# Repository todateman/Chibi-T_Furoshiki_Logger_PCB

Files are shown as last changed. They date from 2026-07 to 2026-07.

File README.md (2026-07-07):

# Chibi-T Furoshiki Logger

M5Stack Basic / Core2 用の車両データロガー拡張基板（モジュール基板）です。

## 概要

本基板は M5Stack の M-BUS コネクタに接続するボトムモジュールとして動作し、以下のデータを収集・記録するためのロガー回路です。

- GNSS（GPS）モジュールからの位置情報（UART）
- 車両 ECU との UART 通信によるデータ
- BME280 センサーによる温湿度・気圧などの環境データ

## 特徴

- M5Stack M-BUS（2×15ピン）接続、Basic / Core2 の両方に対応した Module 基板
  - テンプレートは <https://github.com/botanicfields/KiCad6-Environment> の `M5Stack_module_fdm` を使用
- GNSS（GPS）モジュール接続用の UART 入力
- 車両 ECU との通信用 UART 入力
- Bosch BME280 搭載（I2C接続、アドレス `0x76`）による温湿度・気圧センシング
- MP1584EN-LF-Z による +12V → 5V / 3.3V 降圧レギュレータを内蔵
- ポリヒューズおよびショットキーダイオードによる電源保護

<!-- TODO: 基板写真・回路図スクリーンショットを追加 -->

## 主要部品

| Ref | 部品 | 役割 |
| --- | --- | --- |
| U1 | MP1584EN-LF-Z | 降圧DC-DCコンバータ（+12V → 5V/3.3V） |
| U2 | BME280 | 温湿度・気圧センサー（I2C） |
| J1 | M5Stack M-BUS | M5Stack Basic/Core2 との接続コネクタ |
| D1 | ショットキーダイオード | 電源保護 |
| F1 | ポリヒューズ | 電源保護 |

より詳細な部品表は、KiCad でプロジェクトを開き BOM を出力することで確認できます（後述）。

## リポジトリ構成

```txt
Chibi-T_Furoshiki_Logger.kicad_pro   KiCadプロジェクトファイル
Chibi-T_Furoshiki_Logger.kicad_sch   回路図
Chibi-T_Furoshiki_Logger.kicad_pcb   基板データ
C15051/                              MP1584EN-LF-Z用カスタムライブラリ（シンボル・フットプリント）
logos.pretty/                        シルク印刷用ロゴフットプリント
LICENSE.txt                          ライセンス
```

## 必要な環境

- KiCad 10.0 以降

## 使い方

1. `Chibi-T_Furoshiki_Logger.kicad_pro` を KiCad 10.0 以降で開きます。
2. 回路図・基板データを確認・編集できます。
3. ガーバーデータや部品表（BOM）、部品配置データ（CPL）の生成には、KiCad拡張「[Fabrication Toolkit](https://github.com/bennymeg/Fabrication-Toolkit)」を使用する想定で設定済みです（`fabrication-toolkit-options.json`）。  
   生成したデータは `production/` フォルダに出力されますが、このフォルダは `.gitignore` 対象のためリポジトリには含まれません。  
   各自の環境で生成してください。

## 免責事項

本プロジェクトは個人のホビープロジェクトです。車両への実装・使用は自己責任で行ってください。  
基板の動作および安全性について、いかなる保証も行いません。

## ライセンス

本プロジェクトは [MIT License](LICENSE.txt) の下で公開されています。

Copyright (c) 2026 Tomohiro Kusu

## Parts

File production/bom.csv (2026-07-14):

Designator | Footprint | Quantity | Value | LCSC Part #
C1 | 1206 | 1 | 100uF | C15008
C2, C3, C4 | 0603 | 3 | 22uF | C59461
C5 | 0603 | 1 | 150pF | C1594
C6, C7 | 0805 | 2 | 2.2uF | C377773
C8, C9 | 0402 | 2 | 0.1uF | C1525
D1 | D_SMA | 1 | D_Schottky | C22452
F1 | 1812 | 1 | Polyfuse_Small | C28326708
H1, H2, H3, H4 | BF@MountingHole_3.2mm_M3 | 4 | MountingHole
H5, H6, H7, H8 | BF@MountingHole_2.2mm_M2 | 4 | MountingHole
J1 | BF@M5Stack_MBUS | 1 | M-BUS
L1 | L_Sunlord_SWPA3015S | 1 | 10uH | C45403
R1 | 0603 | 1 | 52.3k | C23198
R2, R4 | 0603 | 2 | 100k | C25803
R3, R5, R6 | 0805 | 3 | 10k | C17414
U1 | SOIC-8_L5.0-W4.0-P1.27-LS6.0-BL-EP2.0 | 1 | MP1584EN-LF-Z | C15051
U2 | Bosch_LGA-8_2.5x2.5mm_P0.65mm_ClockwisePinNumbering | 1 | BME280 | C92489

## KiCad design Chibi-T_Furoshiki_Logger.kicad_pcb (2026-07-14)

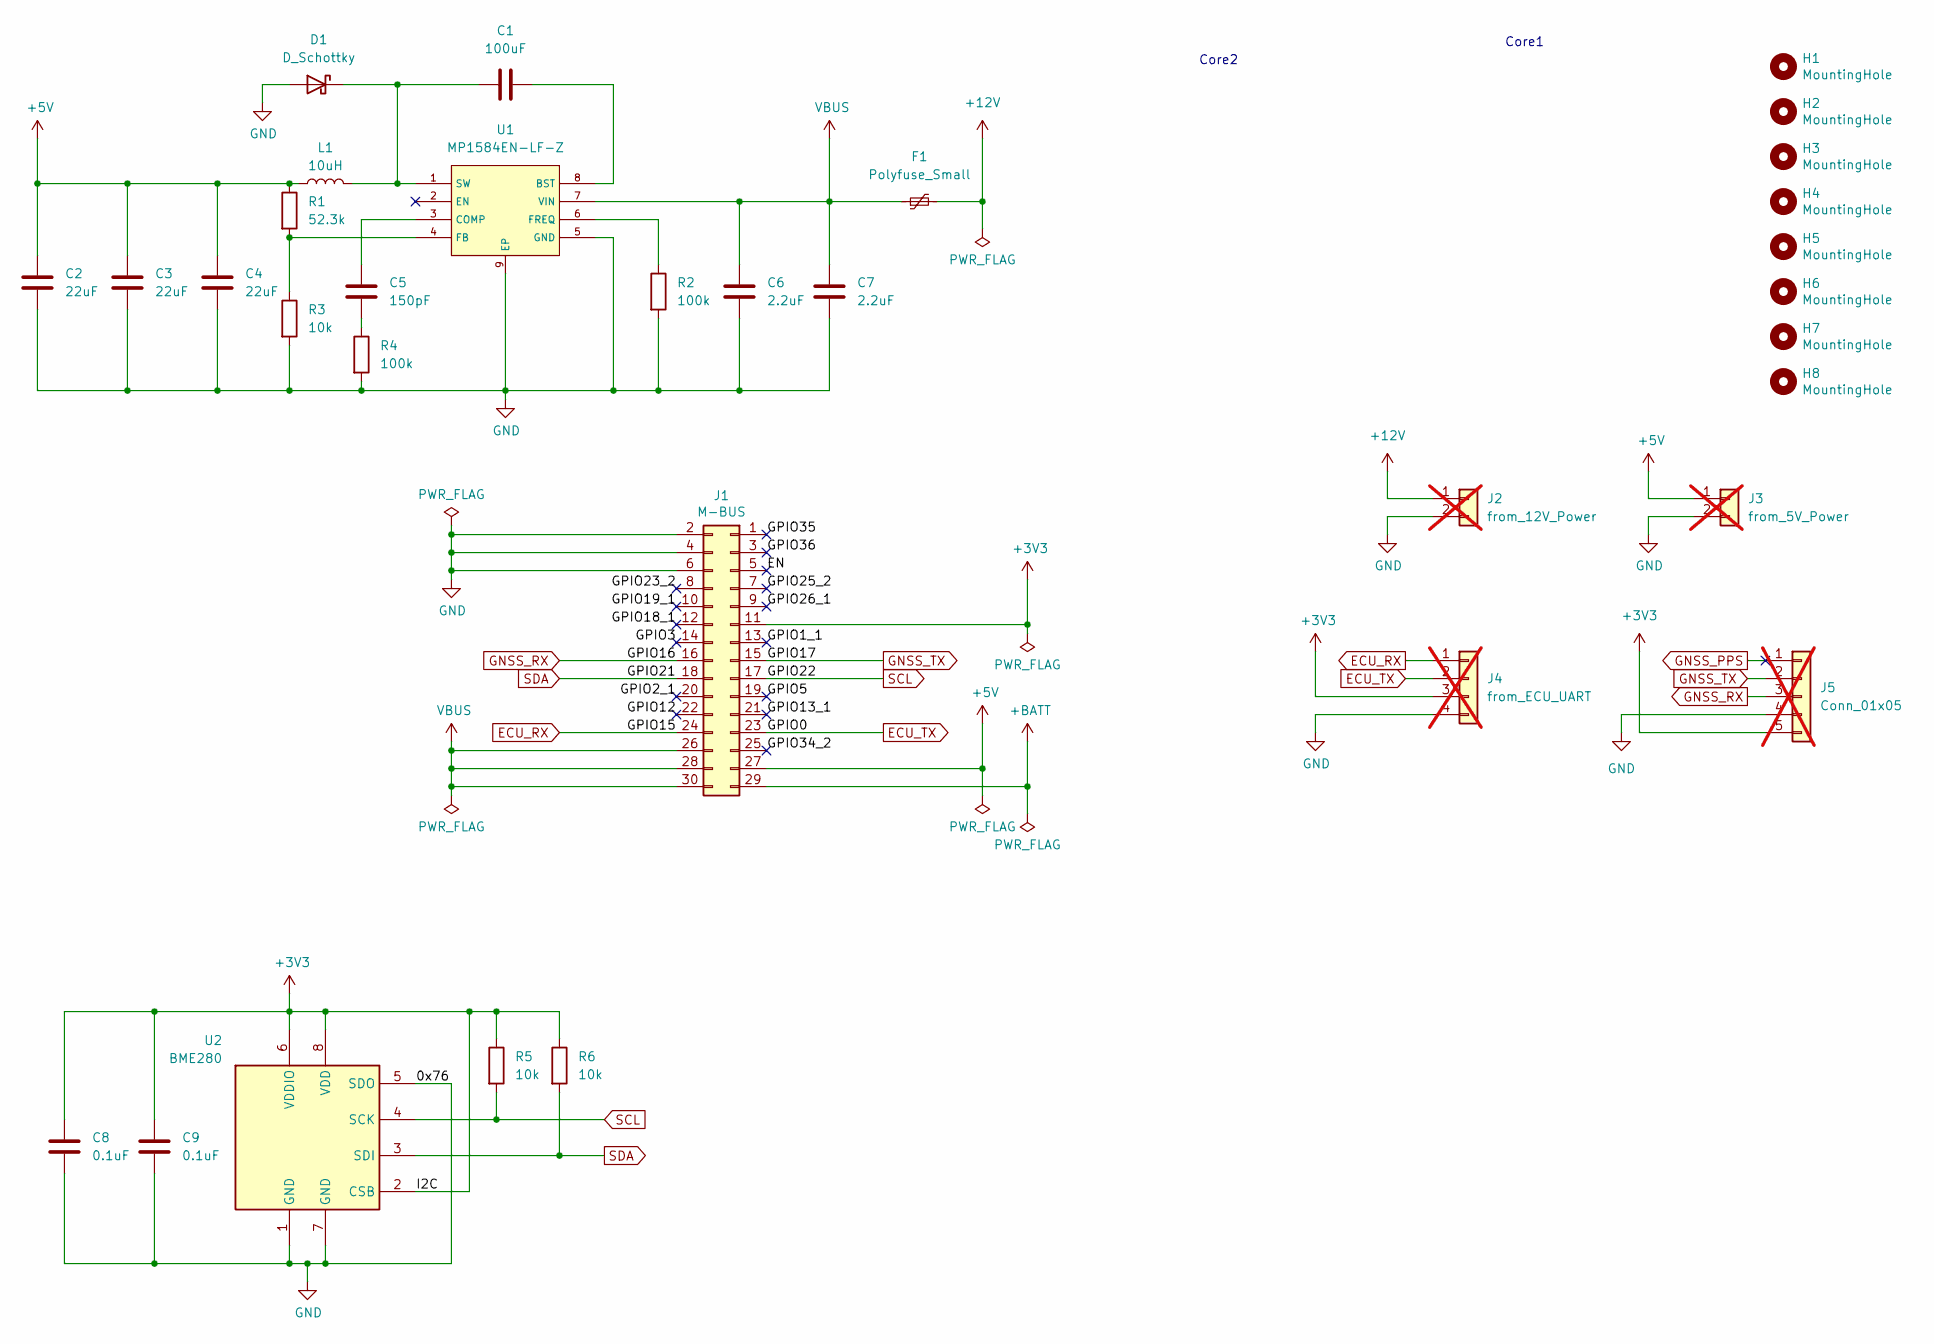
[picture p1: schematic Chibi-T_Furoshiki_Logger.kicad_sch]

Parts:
C1: 100uF; C_1206_3216Metric; LCSC C15008
C2, C3, C4: 22uF; C_0603_1608Metric; LCSC C59461
C5: 150pF; C_0603_1608Metric; LCSC C1594
C6, C7: 2.2uF; C_0805_2012Metric; LCSC C377773
C8, C9: 0.1uF; C_0402_1005Metric; LCSC C1525
D1: D_Schottky; D_SMA; LCSC C22452
F1: Polyfuse_Small; Fuse_1812_4532Metric; LCSC C28326708
H1, H2, H3, H4: MountingHole; BF@MountingHole_3.2mm_M3
H5, H6, H7, H8: MountingHole; BF@MountingHole_2.2mm_M2
J1: M-BUS; BF@M5Stack_MBUS
J2: from_12V_Power; PinSocket_1x02_P2.54mm_Vertical; not fitted
J3: from_5V_Power; PinSocket_1x02_P2.54mm_Vertical; not fitted
J4: from_ECU_UART; PinSocket_1x04_P2.54mm_Vertical; not fitted
J5: Conn_01x05; PinSocket_1x05_P2.54mm_Vertical; not fitted
L1: 10uH; L_Sunlord_SWPA3015S; LCSC C45403
R1: 52.3k; R_0603_1608Metric; LCSC C23198
R2, R4: 100k; R_0603_1608Metric; LCSC C25803
R3, R5, R6: 10k; R_0805_2012Metric; LCSC C17414
U1: MP1584EN-LF-Z; SOIC-8_L5.0-W4.0-P1.27-LS6.0-BL-EP2.0; Manufacturer Part MP1584EN-LF-Z; LCSC C15051
U2: BME280; Bosch_LGA-8_2.5x2.5mm_P0.65mm_ClockwisePinNumbering; LCSC C92489

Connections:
/EN: J1.5
/EN_1: J1.5
/EN_2: J1.5
/GPIO1_1: J1.13
/GPIO1_1_1: J1.13
/GPIO1_1_2: J1.13
/GPIO2_1: J1.20
/GPIO2_1_1: J1.20
/GPIO2_1_2: J1.20
/GPIO3: J1.14
/GPIO3_1: J1.14
/GPIO3_2: J1.14
/GPIO5: J1.19
/GPIO5_1: J1.19
/GPIO5_2: J1.19
/GPIO12: J1.22
/GPIO12_1: J1.22
/GPIO12_2: J1.22
/GPIO13_1: J1.21
/GPIO13_1_1: J1.21
/GPIO13_1_2: J1.21
/GPIO18_1: J1.12
/GPIO18_1_1: J1.12
/GPIO18_1_2: J1.12
/GPIO19_1: J1.10
/GPIO19_1_1: J1.10
/GPIO19_1_2: J1.10
/GPIO23_2: J1.8
/GPIO23_2_1: J1.8
/GPIO23_2_2: J1.8
/GPIO25_2: J1.7
/GPIO25_2_1: J1.7
/GPIO25_2_2: J1.7
/GPIO26_1: J1.9
/GPIO26_1_1: J1.9
/GPIO26_1_2: J1.9
/GPIO34_2: J1.25
/GPIO34_2_1: J1.25
/GPIO34_2_2: J1.25
/GPIO35: J1.1
/GPIO35_1: J1.1
/GPIO35_2: J1.1
/GPIO36: J1.3
/GPIO36_1: J1.3
/GPIO36_2: J1.3
ECU_RX: J1.24, J4.1
ECU_TX: J1.23, J4.2
GNSS_PPS: J5.1
GNSS_RX: J1.16, J5.3
GNSS_TX: J1.15, J5.2
unnamed: C5.1, R4.1
unnamed: C1.1, D1.1 (K), L1.2, U1.1 (SW)
unnamed: C1.2, U1.8 (BST)
unnamed: C5.2, U1.3 (COMP)
unnamed: R1.2, R3.1, U1.4 (FB)
unnamed: R2.1, U1.6 (FREQ)
SCL: J1.17, R5.2, U2.4 (SCK)
SDA: J1.18, R6.2, U2.3 (SDI)

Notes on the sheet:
Core1
Core2

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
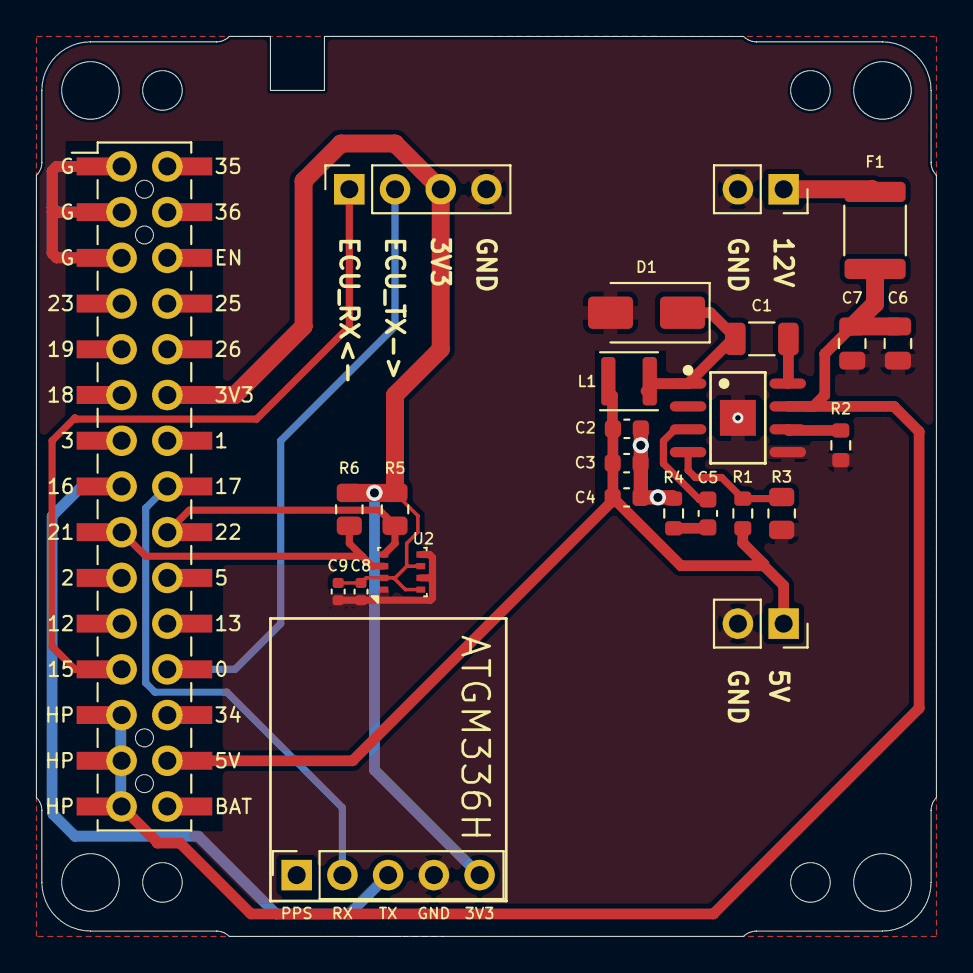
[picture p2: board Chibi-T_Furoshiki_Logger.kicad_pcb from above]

Board: 2 copper layers, 50.0 x 50.0 mm, 33 parts (0 on the bottom side), 17 nets.

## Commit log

2026-07-07 feature: README.mdを追加し、プロジェクトの概要と使い方を記述
2026-07-14 feature: 回路図のバージョンを2.00に更新し、部品L1の情報を追加 BOM、デザインator、ネットリスト、位置情報を新規作成
    [Chibi-T_Furoshiki_Logger.kicad_pcb, Chibi-T_Furoshiki_Logger.kicad_sch, bom.csv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]
2026-07-14 fix: R5およびR6のBOMを修正
    [Chibi-T_Furoshiki_Logger.kicad_pcb, Chibi-T_Furoshiki_Logger.kicad_sch, bom.csv]
